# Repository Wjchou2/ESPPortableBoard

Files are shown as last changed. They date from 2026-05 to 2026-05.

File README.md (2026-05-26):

# ESPPortableBoard
Screenshot 2026-05-26 at 10 57 58 AM
<br>
<br>
A portable devboard designed to be a small customizable gadget. It includes 3 Buttons, a 0.91 inch OLED screen and is power by an ESPRESSIF ESP32-WROOM-32E-N4. 
Power is from a usb port.

This project was originally meant to be a mini mp4 player, but it can also be customized, the buttons used for control and the small screen for display. 

Other Features:
- Power indicator LEDS
- Boot/RST Buttons
- USB-C Powered
- Micro SD Card slot for audio, image, data storage.

[See Kicanvas Link Here!
](https://kicanvas.org/?repo=https%3A%2F%2Fgithub.com%2FWjchou2%2FESPPortableBoard%2Ftree%2Fmain%2Fkicad)

# Schematic
Screenshot 2026-05-10 at 11 50 49 AM

# PCB
Screenshot 2026-05-26 at 11 58 34 AM

Screenshot 2026-05-26 at 11 58 51 AM

# Case
Screenshot 2026-05-26 at 12 16 14 PM
Screenshot 2026-05-26 at 3 07 22 PM

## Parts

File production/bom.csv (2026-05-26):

Designator | Footprint | Quantity | Value | LCSC Part #
C1, C2, C4 | 0603 | 3 | 1uF
C3 | 0603 | 1 | 100nF
C5, C6 | 0603 | 2 | 0.1uF
C7 | 0603 | 1 | 10uF
D1, D2 | 0603 | 2 | LED
OLED1 | OLED-TH_L38.0-W12.0_HS91L02W2C01 | 1 | HS91L02W2C01 | C5248081
R10, R11 | 0603 | 2 | 5.1k
R3, R4, R5, R6, R7, R8, R9 | 0603 | 7 | 10k
SIM1 | SIM-SMD_8P-1040310811 | 1 | 1040310811 | C585350
SW1, SW2 | KEY-SMD_L4.0-W3.0-LS4.9-1 | 2 | SW_Push | C49234124
SW3, SW4, SW5 | SW-SMD_SH-6X6X4.5H-TP | 3 | SW_Push | C42416254
U1 | SOT-23-5 | 1 | AP2112K-3.3
U2 | ESP32-WROOM-32E | 1 | ESP32-WROOM-32E
U3 | SOIC-16_3.9x9.9mm_P1.27mm | 1 | CH340C
USB1 | USB-C-SMD_TYPE-C-16PIN-2MD-073 | 1 | TYPE-C 16PIN 2MD | C2765186

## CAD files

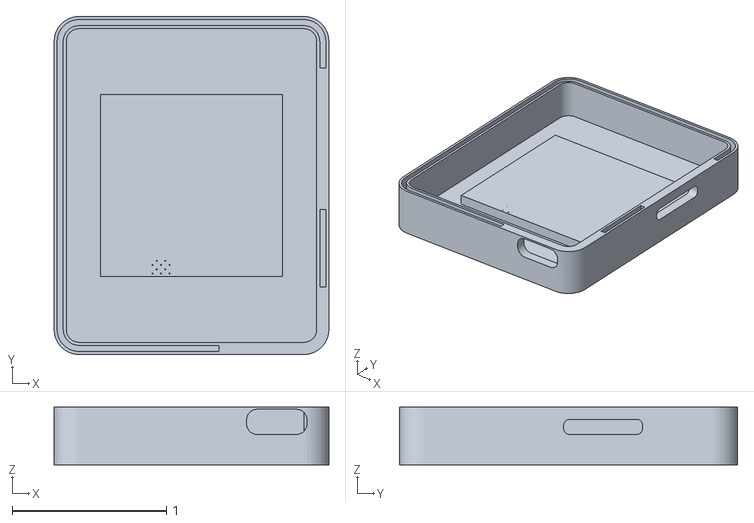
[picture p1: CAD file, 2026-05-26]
CaseSTLs/Case.stl
1.78 x 2.19 x 0.374

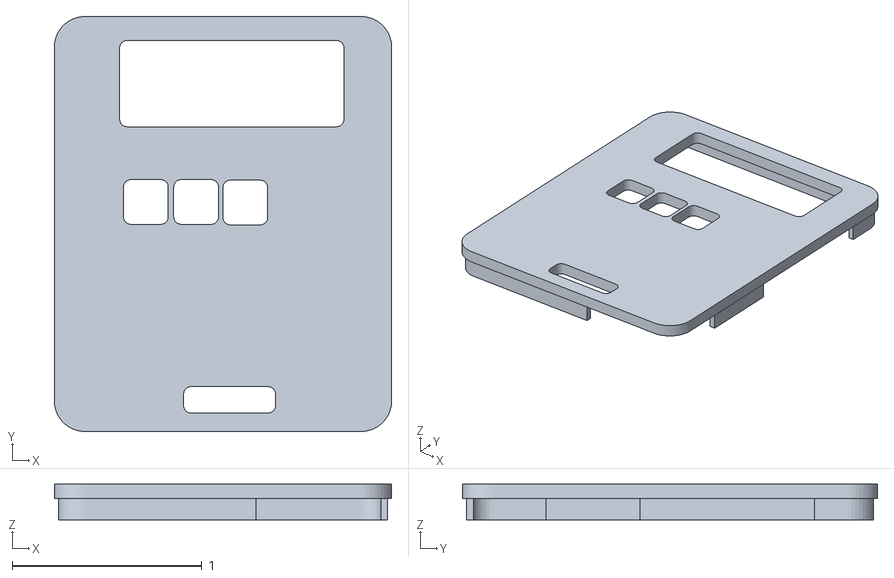
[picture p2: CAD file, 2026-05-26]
CaseSTLs/Lid.stl
1.78 x 2.19 x 0.189

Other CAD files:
CaseSTLs/ESPCASE.f3z

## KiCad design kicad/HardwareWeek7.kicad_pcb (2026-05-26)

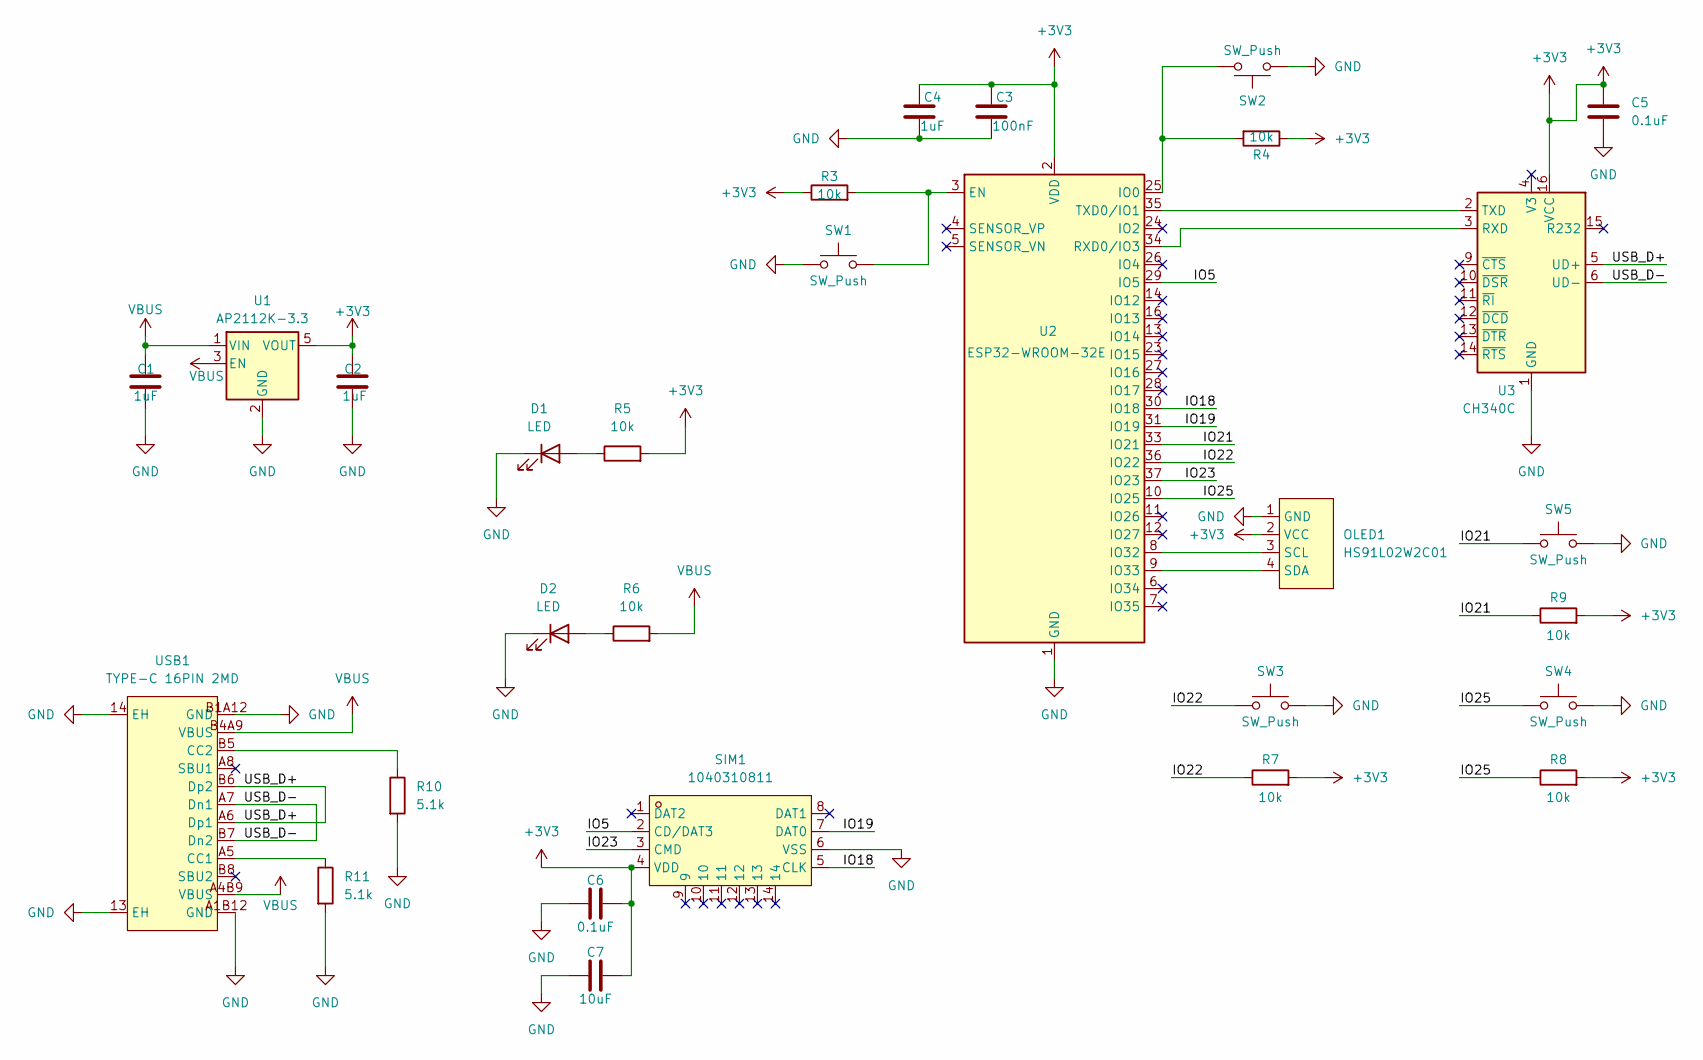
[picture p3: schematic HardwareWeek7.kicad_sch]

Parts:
C1, C2, C4: 1uF; C_0603_1608Metric; LCSC Part C29936
C3: 100nF; C_0603_1608Metric; LCSC Part C14663
C5, C6: 0.1uF; C_0603_1608Metric; LCSC Part C14663
C7: 10uF; C_0603_1608Metric; LCSC Part C96446
D1, D2: LED; LED_0603_1608Metric; LCSC Part C19171390
OLED1: HS91L02W2C01; OLED-TH_L38.0-W12.0_HS91L02W2C01; MPN HS91L02W2C01; LCSC Part C5248081
R3, R4, R5, R6, R7, R8, R9: 10k; R_0603_1608Metric; LCSC Part C2906982
R10, R11: 5.1k; R_0603_1608Metric; LCSC Part C2907044
SIM1: 1040310811; SIM-SMD_8P-1040310811; MPN 1040310811; LCSC Part C585350
SW1, SW2: SW_Push; KEY-SMD_L4.0-W3.0-LS4.9-1; LCSC Part C49234124
SW3, SW4, SW5: SW_Push; SW-SMD_SH-6X6X4.5H-TP; LCSC Part C42416254
U1: AP2112K-3.3; SOT-23-5; LCSC Part C51118
U2: ESP32-WROOM-32E; LCSC Part C701341
U3: CH340C; SOIC-16_3.9x9.9mm_P1.27mm; LCSC Part C84681
USB1: TYPE-C 16PIN 2MD; USB-C-SMD_TYPE-C-16PIN-2MD-073; MPN TYPE-C 16PIN 2MD(073); LCSC Part C2765186

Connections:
+3V3: C2.1, C3.2, C4.2, C5.1, C6.2, C7.2, OLED1.2 (VCC), R3.1, R4.1, R5.2, R7.2, R8.2, R9.2, SIM1.4 (VDD), U1.5 (VOUT), U2.2 (VDD), U3.16 (VCC)
/IO5: SIM1.2 (CD/DAT3), U2.29 (IO5)
/IO18: SIM1.5 (CLK), U2.30 (IO18)
/IO19: SIM1.7 (DAT0), U2.31 (IO19)
/IO21: R9.1, SW5.1, U2.33 (IO21)
/IO22: R7.1, SW3.1, U2.36 (IO22)
/IO23: SIM1.3 (CMD), U2.37 (IO23)
/IO25: R8.1, SW4.1, U2.10 (IO25)
/USB_D+: U3.5 (UD+), USB1.A6 (Dp1), USB1.B6 (Dp2)
/USB_D-: U3.6 (UD-), USB1.A7 (Dn1), USB1.B7 (Dn2)
GND: C1.2, C2.2, C3.1, C4.1, C5.2, C6.1, C7.1, D1.1 (K), D2.1 (K), OLED1.1 (GND), R10.2, R11.2, SIM1.6 (VSS), SW1.1, SW2.1, SW3.2, SW4.2, SW5.2, U1.2 (GND), U2.1 (GND), U2.15 (GND), U2.38 (GND), U2.39 (GND), U3.1 (GND), USB1.13 (EH), USB1.14 (EH), USB1.A1B12 (GND), USB1.B1A12 (GND)
unnamed: D1.2 (A), R5.1
unnamed: D2.2 (A), R6.1
unnamed: OLED1.3 (SCL), U2.8 (IO32)
unnamed: OLED1.4 (SDA), U2.9 (IO33)
unnamed: R3.2, SW1.2, U2.3 (EN)
unnamed: R4.2, SW2.2, U2.25 (IO0)
unnamed: U2.34 (RXD0/IO3), U3.3 (RXD)
unnamed: U2.35 (TXD0/IO1), U3.2 (TXD)
unnamed: R11.1, USB1.A5 (CC1)
unnamed: R10.1, USB1.B5 (CC2)
VBUS: C1.1, R6.2, U1.1 (VIN), U1.3 (EN), USB1.A4B9 (VBUS), USB1.B4A9 (VBUS)

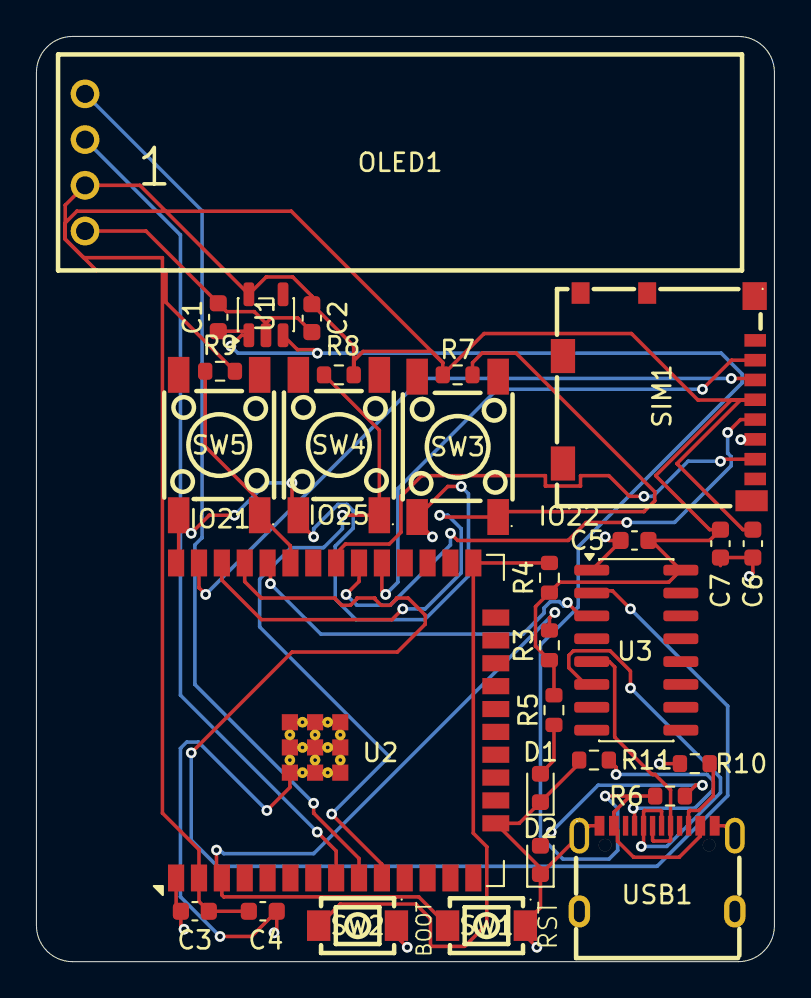
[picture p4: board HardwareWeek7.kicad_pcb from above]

Board: 2 copper layers, 41.0 x 51.4 mm, 29 parts (0 on the bottom side), 22 nets.
